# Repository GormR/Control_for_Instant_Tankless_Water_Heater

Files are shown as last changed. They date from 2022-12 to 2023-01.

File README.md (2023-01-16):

(für Deutsch bitte runterscrollen)

# Controller for Instant or Tankless Water Heater

# Safety Warning

This project deals with mains voltage. Make sure you understand what you are doing. Please read the safety warning below carefully.

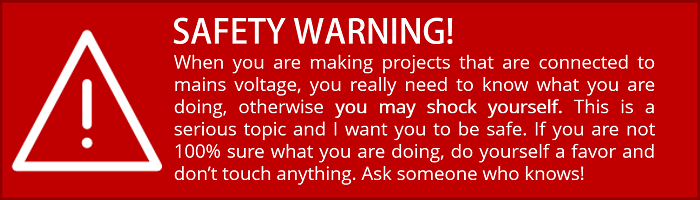
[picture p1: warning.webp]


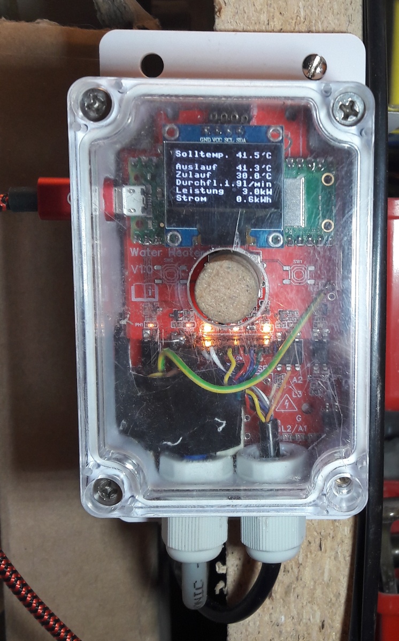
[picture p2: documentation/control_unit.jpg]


[Link to EasyEDA project](https://oshwlab.com/goronb/imu-for-agopengps_copy_copy_copy)

Housing:

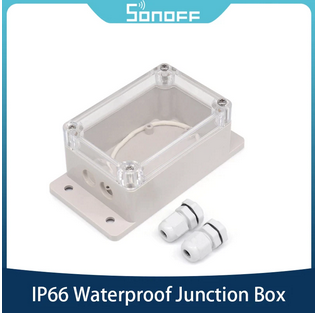
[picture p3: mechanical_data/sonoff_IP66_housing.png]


e. g.: https://de.aliexpress.com/item/1005004819429222.html

Flow meter and temperature sensor:

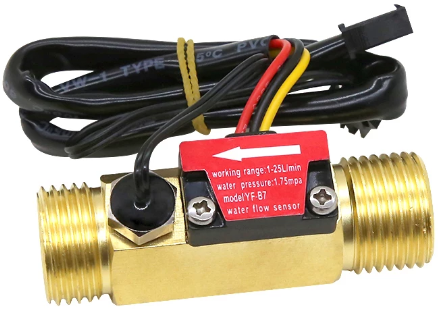
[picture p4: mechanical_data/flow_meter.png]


e. g.: https://de.aliexpress.com/item/1005004532077576.html

Suitable triac: BTA40-600

https://www.st.com/resource/en/datasheet/btb41.pdf

Suitable instant / tankless water heater:

e. g. CLAGE MPH6 5,7 kW 230V (e. g. via Amazon)

* to be translated 

# Elektronische Regelung für einen Durchlauferhitzer

Warnung! Nicht nachbauen - dieses Projekt verwendet Netzspannung und Wasser. Bei unsachgemäßem Umgang besteht Lebensgefahr! Ferner kann hoher Sachschaden entstehen!



Die Elektronik regelt zusammen mit einem oder zwei externen Triacs und einem Durchflussmesser/Temperatursensor die Wassertemperatur eines elektrischen Durchlauferhitzers. Diese Durchlauferhitzer gibt es sowohl einphasig (dann oft als "Klein-Durchlauferhitzer" bezeichnet), als auch dreiphasig. Der Anschluss ist dementsprechend zweipolig oder dreipolig (dreiphasige Durchlauferhitzer sind als Dreieck geschaltet und benötigen keinen Nullleiter), und zur Regelung benötigt entweder einen oder zwei extern zu montierende Triacs.

Solange Triacs und Durchfluss-/Temperaturmesser nicht im Durchlauferhitzer eingebaut werden sollen, ist kein Eingriff in das Gerät notwendig.

Sicherheitseinrichtungen des Durchlauferhitzers dürfen in keinem Fall außer Kraft gesetzt werden!

Aufbau:
Am Kaltwasserzulauf wird ein Durchfluss-/Temperaturmesser angebracht. Dessen Gehäuse kann gleichzeitig zur Kühlung des oder der Triacs dienen. Hier auf perfekten Wärmeübergang achten! Ein Strom von 1A verursacht eine Verlustleistung von ca. 1.2W im Triac. Diese Leistung dient zwar auch der Aufheizung des Wassers, aber bei 40A müssen rund 50W abgeführt werden. 

Es muss eine Messingplatte angelötet werden, die den oder die Triacs isoliert aufnehmen kann. Diese Messingplatte muss mit PE verbunden sein mit einem 4mm²-Draht. Zum Anlöten der Platte muss natürlich die Turbine im Inneren sowie der Hallsensor und der Temperatursensor demontiert werden.

Nach erfolgtem Aufbau sollte die Funktion zunächst mit Hilfe einer klassischen Glühlampe anstelle des Heizelementes überprüft werden.

Regelung:
Die notwendige elektrische Energie ist direkt proportional zum Durchfluss und zur Temperaturdifferenz zwischen der Temperatur des einströmenden Wassers und der Wunschtemperatur:

Power = p x Wasserdurchfluss x deltaT

Die Proportionalitätskonstante (in Python-Script auch "p") muss empirisch ermittelt werden, solange nicht exakt dieselben Teile verwendet werden, wie in diesem Versuchsaufbau. Auf den Temperatursensor am Ausgang kann für die Temperaturregeleung komplett verzichtet werden, er ist aber zum Finden der Proportionalitätskonstante sehr hilfreich, und die Ausgangstemperatur kann so zur Kontrolle auf dem Display angezeigt werden. 

Auch muss die Formel zur Berechnung der Temperatur händisch ermittelt werden, falls nicht derselbe Sensor verwendet wird. Dazu wird der Sensor in ein Wasserbad gehängt und die Rohdaten des ADCs über Temperatur ermittelt. In einer Tabellenkalkulation kann man dann die optimale Formel ausprobieren. Eine geeignete Kalkulationstabelle befindet sich im Ordner "documentation". Ggf. die drei Konstanten k0, k1 und k2 im Python-Script anpassen.

Gehäuse:



z. B.: https://de.aliexpress.com/item/1005004819429222.html

Durchflussmesser und Temperatursensor:



z. B.: https://de.aliexpress.com/item/1005004532077576.html

Geeigneter Triac: BTA40-600
https://www.st.com/resource/en/datasheet/btb41.pdf

Durchlauferhitzer:
z. B. CLAGE MPH6 Klein-Durchlauferhitzer 5,7 kW 230V, druckfest, Untertisch (z. B. bei Amazon)

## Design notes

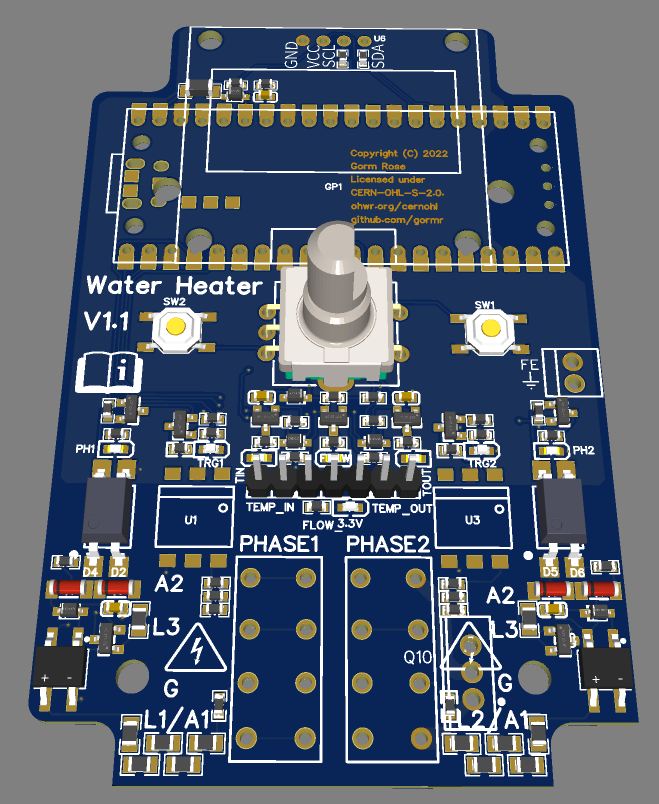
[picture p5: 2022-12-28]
3D.png

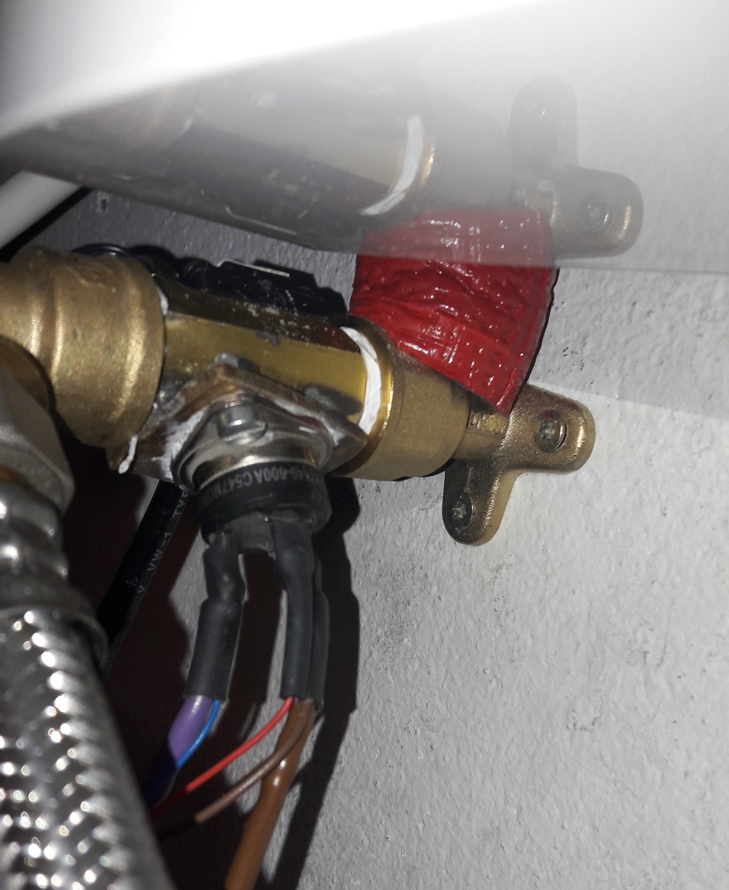
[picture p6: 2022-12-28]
documentation/triac.jpg

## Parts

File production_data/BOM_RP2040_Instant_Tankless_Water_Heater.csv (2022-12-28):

ID | Name | Designator | Footprint | Quantity | Manufacturer Part | Manufacturer | Supplier | Supplier Part | Price
1 | Screw_Terminal_1x01 | FE | 640454-2P | 1
2 | SSH1106 128X64 1.3 I2C DISPLAY MODULE | U6 | SSH1106 128X64 1.3 I2C OLED DISPLAY MODULE | 1
3 | A2541WV-3P_C609572 | FLOW_ | HDR-TH_3P-P2.54-V-M | 1 | A2541WV-3P | CJT(Changjiang Connectors) | LCSC | C609572 | 0.054
4 | A2541WV-2P | TEMP_IN,TEMP_OUT | HDR-TH_P2.54-H-M_A2541WV-2P | 2 | A2541WV-2P | CJT(Changjiang Connectors) | LCSC | C225477 | 0.035
5 | 0603White light_C2290 | 3.3V | LED0603-R-RD_WHITE | 1 | 0603White light | KENTO | LCSC | C2290
6 | 19-213/Y2C-CQ2R2L/3T(CY) | FLOW,PH1,PH2,TIN,TOUT | LED0603-R-RD | 5 | 19-213/Y2C-CQ2R2L/3T(CY) | EVERLIGHT | LCSC | C72038 | 0.022
7 | XL-1608UOC-06 | TRG1,TRG2 | LED0603-R-RD_ORANGE | 2 | XL-1608UOC-06 | XINGLIGHT(成兴光) | LCSC | C965800 | 0.005
8 | 100uF | C1 | C1206 | 1 | CL31A107MQHNNNE | SAMSUNG | LCSC | C15008 | 0.069
9 | 100n | C2,C4 | C0603 | 2 |  |  | LCSC
10 | 100nF | C3,C6,C7 | C0603 | 3 | CC0603KRX7R9BB104 | YAGEO | LCSC | C14663 | 0.002
11 | MB10F-46 | D1,D8 | MBF_L4.8-W3.9-P2.50-LS6.7-BL | 2 | MB10F-46 | MDD | LCSC | C114017 | 0.014
12 | ZMM5V6 | D2,D4,D5,D6 | LL-34_L3.5-W1.5-RD | 4 | ZMM5V6 | SEMTECH | LCSC | C8062 | 0.018
13 | 1N5819WS | D7,D9,D10,D11,D12,D3 | SOD-323_L1.8-W1.3-LS2.5-RD | 6 | 1N5819WS | Guangdong Hottech | LCSC | C191023 | 0.017
14 | RASPBERRY PI PICO | GP1 | RASPBERRY PI PICO | 1 | RPi Pico | Raspberry Pi Foundation | Raspberry Pi Foundation | RPi Pico
15 | LSF-SMT_5.08_04_180 | PHASE1,PHASE2 | LSF-SMT_5.08_04_180 | 2
16 | LBSS84LT1G | Q1,Q2,Q3,Q4,Q5,Q6,Q7,Q8,Q9 | SOT-23_L2.9-W1.3-P1.90-LS2.4-BR | 9 | LBSS84LT1G | LRC | LCSC | C8492 | 0.024
17 | 220kΩ | R1,R2,R3,R4,R5,R24,R25,R27,R28,R29,R47,R48 | R0805 | 12 | 0805W8F2203T5E | UniOhm | LCSC | C17556 | 0.002
18 | 1kΩ | R6,R7,R8,R9,R21,R22,R23,R26,R42 | R0603 | 9 | 0603WAF1001T5E | UniOhm | LCSC | C21190
19 | 2.2kΩ | R10,R13,R17,R20,R30,R38,R39,R40,R41,R43,R44,R45,R46 | R0603 | 13 | 0603WAF2201T5E | UniOhm | LCSC | C4190 | 0.001
20 | 10kΩ | R11,R12,R18,R19,R31,R32,R33,R34,R35,R36,R37 | R0603 | 11 | 0603WAF1002T5E | UniOhm | LCSC | C25804 | 0.001
21 | 220R | R14,R16 | R0603 | 2 |  |  | LCSC
22 | 1k | R15 | R0603 | 1 |  |  | LCSC
23 | TS-1187A-B-A-B | SW1,SW2,SW3 | SW-SMD_4P-L5.1-W5.1-P3.70-LS6.5-TL-2 | 3 | TS-1187A-B-A-B | XKB Enterprise | LCSC | C318884 | 0.016
24 | PEC11R-4015F-S0024 | SW4 | SW-TH_PEC11R-4XXXF-SXXXX | 1 | PEC11R-4015F-S0024 | BOURNS | LCSC | C143789 | 1.67
25 | MOC3063S | U1,U3 | DIP8SMD | 2
26 | BPC-817S/A | U2,U4 | SOP-4_L6.5-W4.6-P2.54-LS10.2-BR | 2 | BPC-817S/A | Bright LED Elec | LCSC | C231225

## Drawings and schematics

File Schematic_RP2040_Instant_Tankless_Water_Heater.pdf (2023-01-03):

## LED colors: white: power

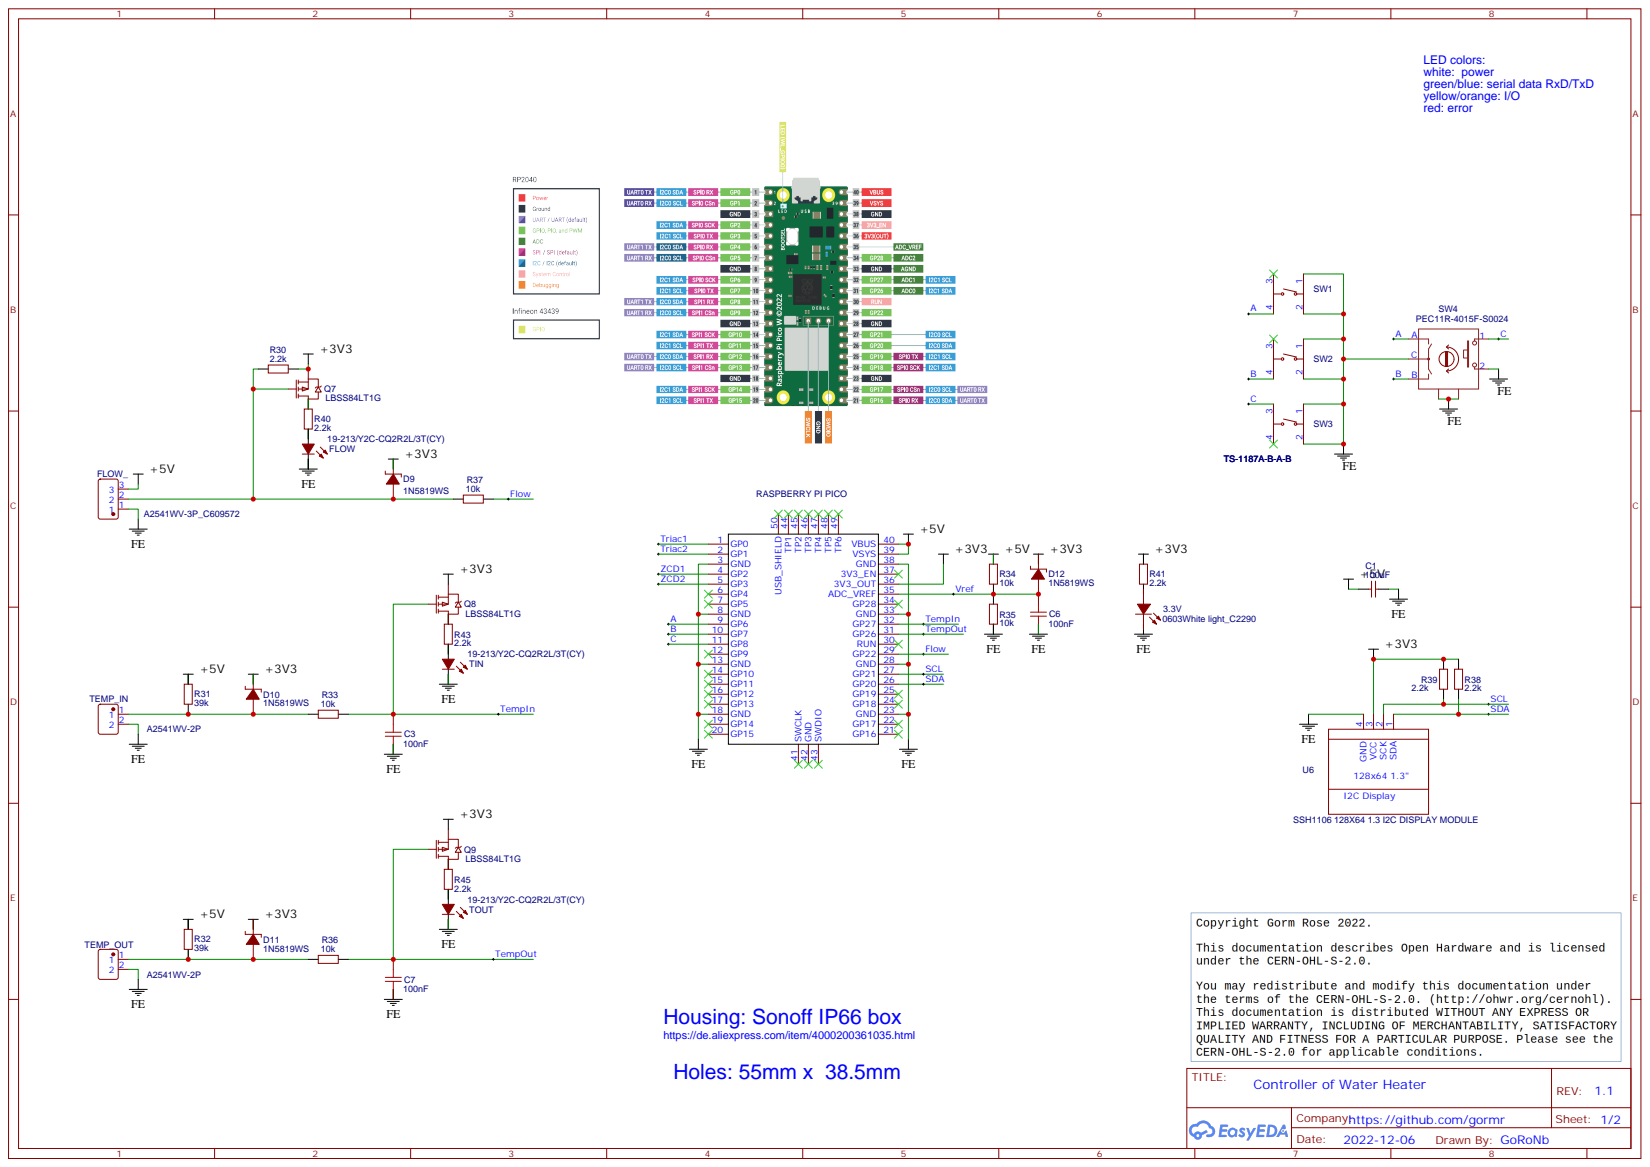
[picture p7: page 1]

green/blue: serial data RxD/TxD
yellow/orange: I/O
red: error

Housing: Sonoff IP66 box
https://de.aliexpress.com/item/4000200361035.html
Holes: 55mm x 38.5mm

Company:https://github.com/gormr

1

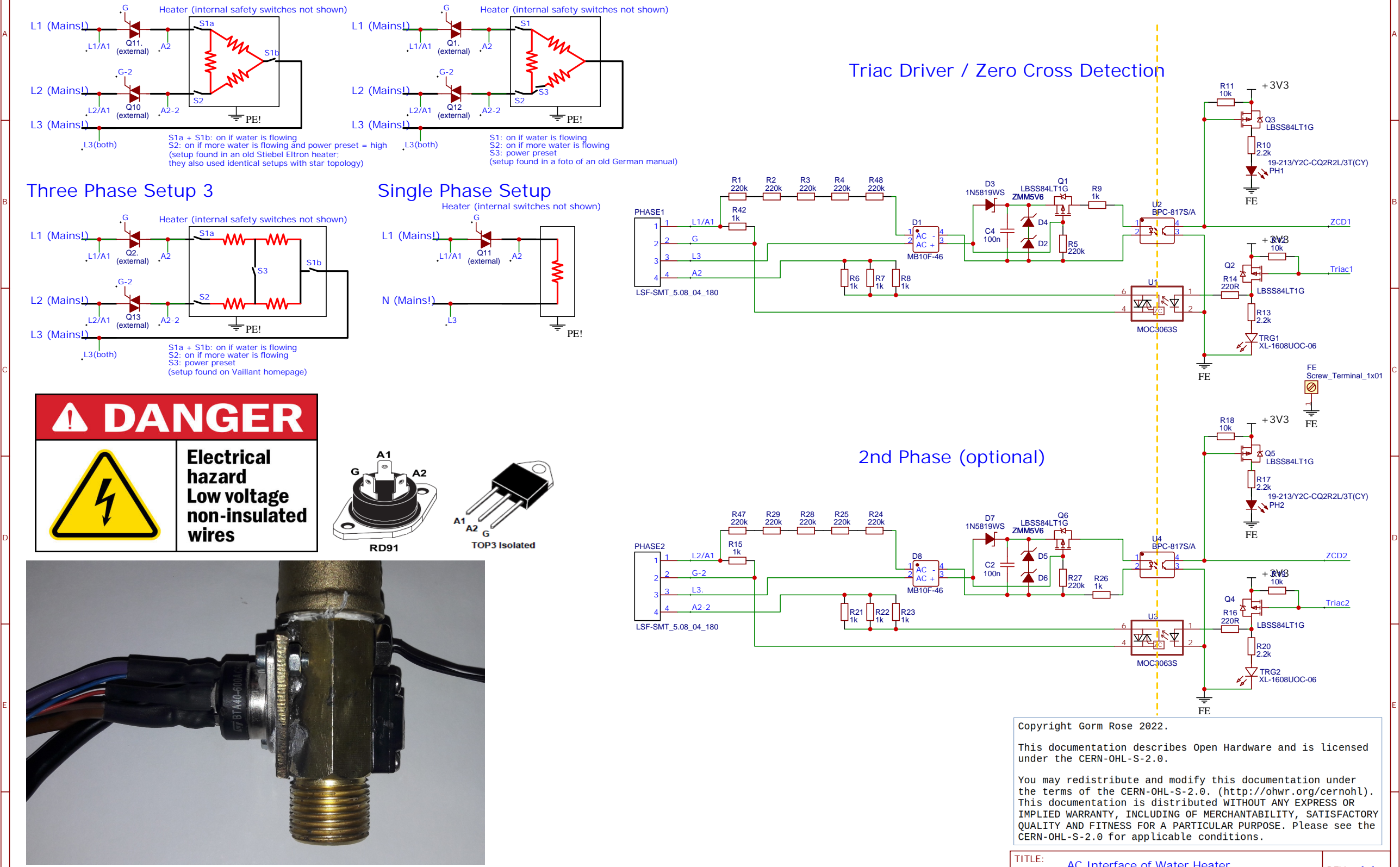
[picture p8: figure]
TITLE:; Triac Driver / Zero Cross Detection; MOC3063S; LSF-SMT_5.08_04_180; PHASE1; ZMM5V6; ZCD1; Triac1; LBSS84LT1G; Triac2; ZCD2; PHASE2; 2nd Phase (optional); XL-1608UOC-06; TRG1; TRG2; BPC-817S/A; Screw_Terminal_1x01; (external); L1 (Mains!); L2 (Mains!); L3 (Mains!); L3(both); N (Mains!); Heater (internal switches not shown); Single Phase Setup; S1a + S1b: on if water is flowing; S2: on if more water is flowing; S1: on if water is flowing; PE! ⁽external); S3: power preset; (setup found on Vaillant homepage); Three Phase Setup 3

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
AC Interface of Water Heater | REV: 1.1
Date: | 2022-12-06

Sheet: 2/2
Drawn By: GoRoNb

### Company:https://github.com/gormr

### Triac with Mounting Plate, Temperature Sensor and Flow Meter Mounting Plate must be connected to Protective Earth!

Unmount all inner and outer plastic parts before soldering the mounting plate to the tube!!

### Example uses ST BTA40-600 brown power wire + signal wire: Lx/A1 purple power wire + blue signal wire: A2 red signal wire: G

# Three Phase Setup 1

Heater (internal safety switches not shown)

S2: on if more water is flowing and power preset = high (setup found in an old Stiebel Eltron heater;
(setup found in a foto of an old German manual)

Heater (internal safety switches not shown)

# Three Phase Setup 2

Heater (internal safety switches not shown)

There are many different setups for 3-phase heaters. Electronical ones use 2 to 5 triacs!

they also used identical setups with star topology)

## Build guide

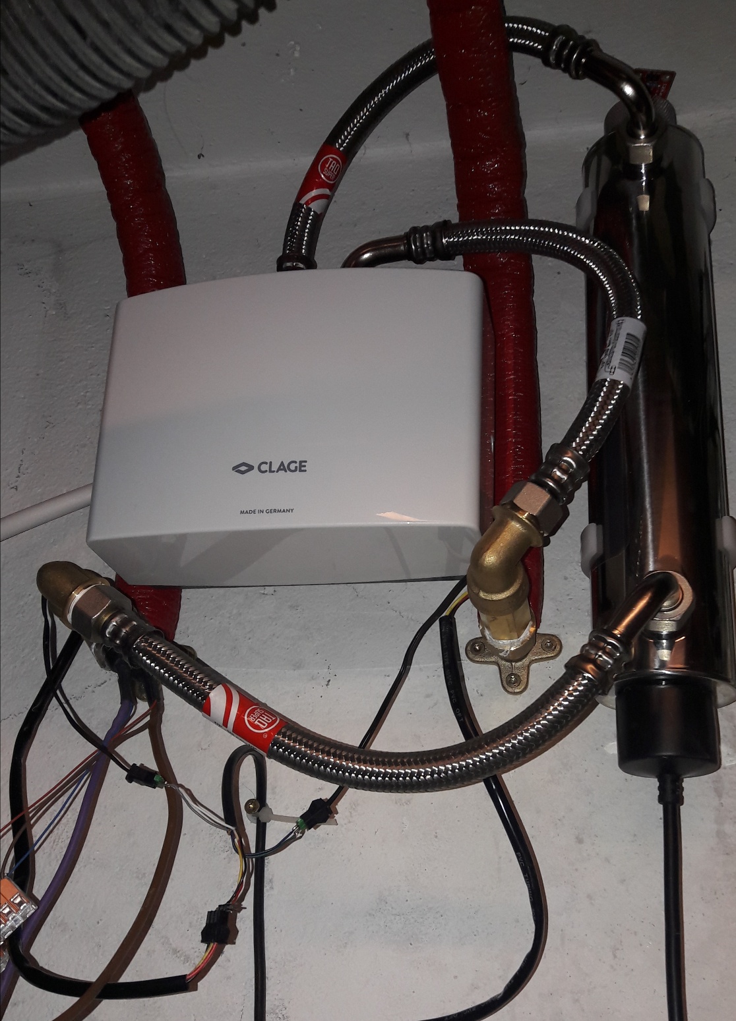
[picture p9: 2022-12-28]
documentation/during_installation.jpg

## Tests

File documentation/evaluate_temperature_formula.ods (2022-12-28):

Temperature | ADC value | Delta | Av. Delta of five | 0x10000 - ADC value | Temperature calculated by formular | Deviation | Av. Delta of five | Quotient Linear | Quotient Square | Offset
17 | 65000 | 600 |  | 536 | 16.9880882004465 | 0.01191179955346 |  | 1390 | 116000000 | 16.6
18 | 64400 | 1800 |  | 1136 | 17.4283911525676 | 0.571608847432398
19 | 62600 | 1400 | 1260 | 2936 | 18.7865413882411 | 0.213458611758867 | 0.131790385512278
20 | 61200 | 1700 | 1380 | 4336 | 19.8815011500868 | 0.11849884991317 | 0.1452403929546
21 | 59500 | 800 | 1340 | 6036 | 21.2565261810965 | -0.256526181096504 | 0.043319465145123
22 | 58700 | 1200 | 1340 | 6836 | 21.9208381632349 | 0.079161836765071 | -0.065937587695363
23 | 57500 | 1600 | 1240 | 8036 | 22.937995791615 | 0.062004208385012 | -0.207539468122056
24 | 55900 | 1400 | 1260 | 9636 | 24.3328266524436 | -0.332826652443565 | -0.294947178367653
25 | 54500 | 1200 | 1200 | 11036 | 25.5895105522203 | -0.589510552220297 | -0.418359239890849
26 | 53300 | 900 | 1040 | 12236 | 26.6935647323245 | -0.693564732324486 | -0.509999626891592
27 | 52400 | 900 | 900 | 13136 | 27.5378984708509 | -0.537898470850909 | -0.477605203671548
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

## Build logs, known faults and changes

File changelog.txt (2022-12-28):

V1.0
- first release 

V1.1
- bugfixes - no new features

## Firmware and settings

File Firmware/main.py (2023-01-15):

#  Test code for instant/tankless water heater
#
#
#  copyright 2022 by Gorm Rose
#
#  This example code is licensed under GNU PL V3.0
#

# GP0: Triac1
# GP1: (Triac2)
# GP2: ZCD1
# GP3: (ZCD2)
# GP6: A rotary encode
# GP7: B rotary encode
# GP8: Push rotary encode
# GP20/21: I²C
# GP22: Flow 0..13
# GP26: Temperature out
# GP27: Temperature in
# Vref = external

import _thread  # unfortunately buggy and not working together with pin interrupt 1/2023
from machine import Pin, I2C, ADC
from ssd1306 import SSD1306_I2C
from time import sleep

patterns = [0b00000000000000000000000000000000,  #  0 first phase
            0b10000000000000000000000000000000,  #  1
            0b10000000000000001000000000000000,  #  2
            0b10000000000100000000001000000000,  #  3
            0b10000000100000001000000010000000,  #  4
            0b10000010000010000001000001000000,  #  5
            0b10000100001000001000010000010000,  #  6
            0b10001000010001000010001000010000,  #  7
            0b10001000100010001000100010001000,  #  8
            0b10001001000100100010010001001000,  #  9
            0b10010010001001001001001000100100,  # 10
            0b10010010010010100100100100100100,  # 11
            0b10010100100100101001001010010010,  # 12
            0b10100101001010100101001010010100,  # 13
            0b10010101010010101001010100101010,  # 14
            0b10100101010101010101010010101010,  # 15
            0b10101010101010101010101010101010,  # 16
            0b01011010101010101010101101010101,  # 17
            0b01101010101101010110101011010101,  # 18
            0b01011010110101011010110101101011,  # 19
            0b01101011011011010110110101101101,  # 20
            0b01101101101101011011011011011011,  # 21
            0b01101101110110110110110111011011,  # 22
            0b01110110111011011101101110110111,  # 23
            0b01110111011101110111011101110111,  # 24
            0b01110111101110111101110111101111,  # 25
            0b01111011110111110111101111101111,  # 26
            0b01111101111101111110111110111111,  # 27
            0b01111111011111110111111101111111,  # 28
            0b01111111111011111111110111111111,  # 29
            0b01111111111111110111111111111111,  # 30
            0b01111111111111111111111111111111,  # 31
            0b11111111111111111111111111111111]  # 32

#### µC pin definitions ####

_gate = Pin(0, Pin.OUT)       # gate of power triac: 0 = on
_gate2 = Pin(1, Pin.OUT)      # gate of power triac: 0 = on
_zerocross = Pin(2, Pin.IN)   # 0 = mains zero crossing right now
A = Pin(6, Pin.IN, Pin.PULL_UP)
B = Pin(7, Pin.IN, Pin.PULL_UP)
Button = Pin(8, Pin.IN, Pin.PULL_UP)
_flow = Pin(22, Pin.IN)       # water flow pulses 660 pulses/l
temp_out = ADC(26)
temp_in = ADC(27)

#### user constants ####

HeaterPower = 5.6                 # electrical power of water heater in [kW]
MainsFreq = 50                    # Mains freqency in [Hz]
Ttarget = 41.5                    # TARGET TEMPERATURE in [°C]; preset - can be changed via jogdial
BoostTime = 500 * MainsFreq / 64  # Boost time in [s]; pattern length is 64 half waves
DelayTime = 5 * MainsFreq / 64    # Delay time in [s] before boost starts to avoid boost on minimum consumption and to protect mechanical contacts
p = 1 / 27                        # constant for heating curve: power = p * delta_temperature * waterflow  (higher = steeper)
k0 = 16.6                         # constants for tranforming ADC value to temperature in °C
k1 = 1 / 1390
k2 = 1 / 116000000
PPL = 1020                        # pulses per liter


#### variables ####

cycle = 1       # pattern bit counter
lowhigh = 0     # always two identical bits
power = 0       # values from 0 (off) to 64 (full power on both phases)
TinLP = 0       # temperature LP filter (64 values)
ToutLP = 0
Wflow = 0       # water flow counter
flowcnt = 0
flowhelp = _flow.value()
standbycnt = BoostTime  # counts time of no water consumption in 64/f (f=50Hz in Europe) steps till BoostTime
boost = 0
delay = 0

_gate.value(1)      # init as inactive
_gate2.value(1)     # init as inactive


#### water counter interrupt ####

def callback(_flow):
    global flowcnt
    flowcnt += 1

#_flow.irq(trigger=Pin.IRQ_FALLING, handler=callback)  # remarked due to bug in threads lib


# variables for display values
Tin = 22.2   # temperature measurement in
Tout = 33.3  # temperature measurement out
power = 0    # power level 0..64 (just 0..32 is used for single triac setup)
Wflow = 0    # actual water flow
water = 0    # water sum of one take
energy = 0   # energy counter since last reset

# core 1 -----------------------------------------------------------------------------------------------------

def OLED_display():
    global new_display_data  # baton for displaying
    global Ttarget, Tin, Tout, Wflow, power, energy, standbycnt, water
    global HeaterPower, MainsFreq, BoostTime
    
# OLED display 
    WIDTH = 128
    HIGHT = 64

    i2c = I2C(0, scl=Pin(21), sda=Pin(20), freq=400000)
    oled = SSD1306_I2C(WIDTH, HIGHT, i2c)  # 30ms
    new_display_data = 1

    while True:   
        if new_display_data == 2:
            oled.fill(0)  
            if standbycnt < BoostTime:
                oled.text("Solltemp. %2.1f'C" % Ttarget, 0, 0)  
                oled.text("Auslauf   %2.1f'C" % Tout, 0, 16)  
                oled.text("Zulauf    %2.1f'C" % Tin, 0, 26)
                if Wflow == 0:
                    oled.text("Verbrauch  %4.1fl" % (water/PPL), 0, 36)
                else:
                    oled.text("Durchfl.%1.1fl/min" % (Wflow * 60 * MainsFreq / PPL / 64), 0, 36)
                oled.text("Leistung   %2.1fkW" % (HeaterPower * power / 32), 0, 46)  # 64 instead of 32 for 2 triacs
                oled.text("Strom  %6.1fkWh" % (HeaterPower * energy / 7200 / MainsFreq), 0, 56)
            oled.show()  # 26ms
            new_display_data = 1
        
        sleep(0.05)


# core 0 -----------------------------------------------------------------------------------------------------

new_display_data = 0  # 0: init needed, 1: nothing to display, 2: new data to show
print("Hello World!")
_thread.start_new_thread(OLED_display,())  # run OLED thread on core 1
print("OLED thread started.")
x = 0
a = A.value()
b = B.value()

#### control loop ####

while True:
    if _flow.value() != flowhelp:  # interrupt replacement
        flowcnt += 1
        flowhelp ^= 1
        
    if lowhigh != 0:  # this 'if' ensures, that always two half waves are either on or off (avoids DC on AC net)
        cycle -= 1
        lowhigh = 0
    else:
        lowhigh = 1

    if cycle == 0:  # once every 1.28s @ 50 Hz (1.02s @ 60 Hz)
        cycle = 32
        temp = 0x10000 - (ToutLP >> 6)  # >> 6: temperature LP filter (64 values)
        Tout = k0 + k1 * temp + k2 * temp * temp  # calculate temperature in °C from ADC values
        temp = 0x10000 - (TinLP >> 6)
        Tin  = k0 + k1 * temp + k2 * temp * temp

        TinLP = 0  # reinit counters
        ToutLP = 0
        Wflow = flowcnt
        water += flowcnt
        flowcnt = 0

        if Wflow == 0:  # no water consumption
            boost = 0
            delay = 0
            power = 0
            if standbycnt < BoostTime:
                standbycnt += 1
        else:  # water is flowing
            if boost > 0:
                boost -= 1
            if standbycnt == 0:
                power = int(p * Wflow * (Ttarget - Tin))
            else:
                 if delay < DelayTime and standbycnt >= (BoostTime-5):  # switch-on delay
                     delay += 1
                 else:
                     boost = int((Ttarget - Tin) * standbycnt / 150)
                     standbycnt = 0
            if power < 0:
                power = 0
            if power > 64 or boost > 0:
                power = 64

        if new_display_data == 1:  # print out the new value after OLED is initialized
            new_display_data = 2
        print(Tout, Tin, Wflow, power, standbycnt, boost, delay, water, a, b)

    while _zerocross.value() == 1:    # wait for mains voltage zero crossing
        pass

    if power > 32:
        _gate.value(0)          # trigger triac for the next half wave (10ms)
        energy += 1             # counter this half wave
    else:
        if (patterns[power] & (1 << (cycle - 1))) != 0:
            _gate.value(0)      # trigger triac for the next half wave (10ms)
            energy += 1         # counter this half wave
    sleep(.003)                 # trigger for 3ms
    _gate.value(1)              # then release trigger

#    if power > 32:  # enable these lines for 2-phase setups
#        while _zerocross.value() == 1:  # wait for mains voltage zero crossing (2nd phase must be 120° delayed)
#            pass
#        if (patterns[power - 32] & (1 << (cycle - 1))) != 0 or boost > 0:
#            _gate2.value(0)     # trigger 2nd triac for the next half wave (10ms)
#    sleep(.003)                 # trigger for 3ms
#    _gate2.value(1)             # then release trigger2

    ToutLP += temp_out.read_u16()  # blue/green wires in my case
    TinLP += temp_in.read_u16()    # white/gray wires in my case
    
    # jogdial control
    if a == A.value() and b == B.value() and x != a:  # 10ms debounce filter + change detection 
        print(a,b)
        if a^b != 0 and Ttarget < 60:
            Ttarget += 0.5
        if a^b == 0 and Ttarget > 20:
            Ttarget -= 0.5
        new_display_data = 2
        if standbycnt > BoostTime - 20:
            standbycnt = BoostTime - 20  # OLED on for 20s
        x = a
    a = A.value()
    b = B.value()
    if Button.value() == 0 and standbycnt > BoostTime - 20:
            standbycnt = BoostTime - 20  # OLED on for 20s
            new_display_data = 2
